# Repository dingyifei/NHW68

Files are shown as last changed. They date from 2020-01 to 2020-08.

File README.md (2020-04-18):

# Not Hand Wired 68 Keys

## License

This project (not include ./hardware/KiCad/, ./code, or files with licenses inside them) is using MIT license.

If not specified, the files in ./code are GPL V2

## Code

Code should be functional, haven't push it to QMK or tested on the keyboard yet, compile passed.

## Hardware

I'm attempting to draw the PCB and its my first time drawing a PCB so 0 confidence it will work. I did my research and if you want to use it plz do your own research make sure it works.

I have not yet tested the PCB, the keyboard PCB currently looks like this:

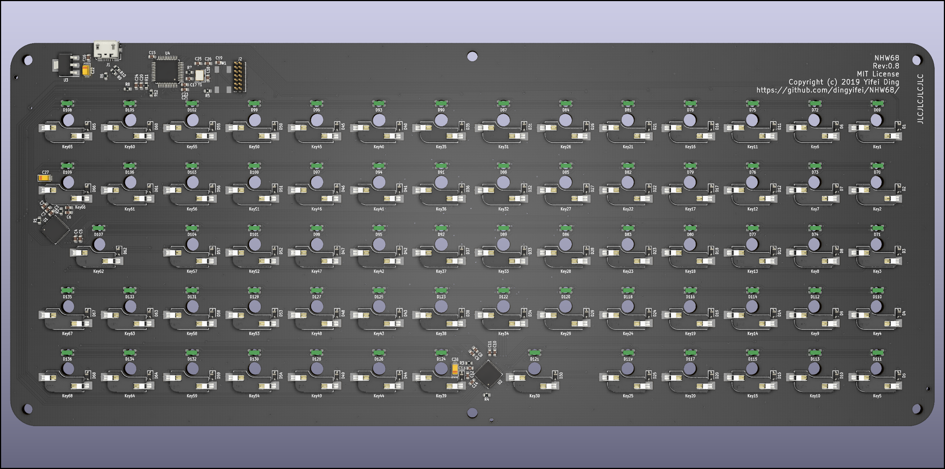
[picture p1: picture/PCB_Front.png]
PCB_Front


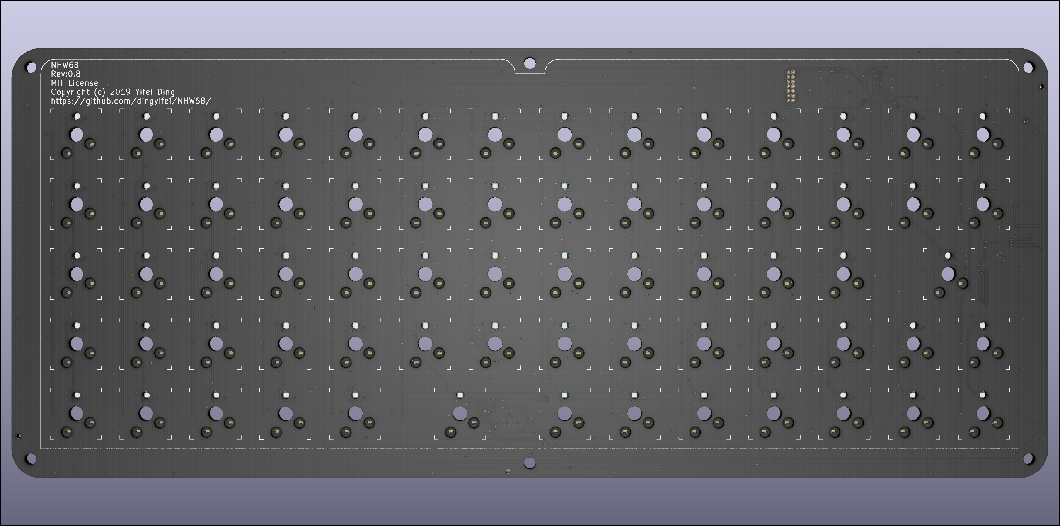
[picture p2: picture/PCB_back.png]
PCB_Back


The keyboard uses STM32F303CCT6, IS31FL3733 and have per Key RGB. 

The RGB is optional since it can work without RGB (I believe most people can live without RGB :p)

Here is the fusion 360 3d mode, I think it is good enough

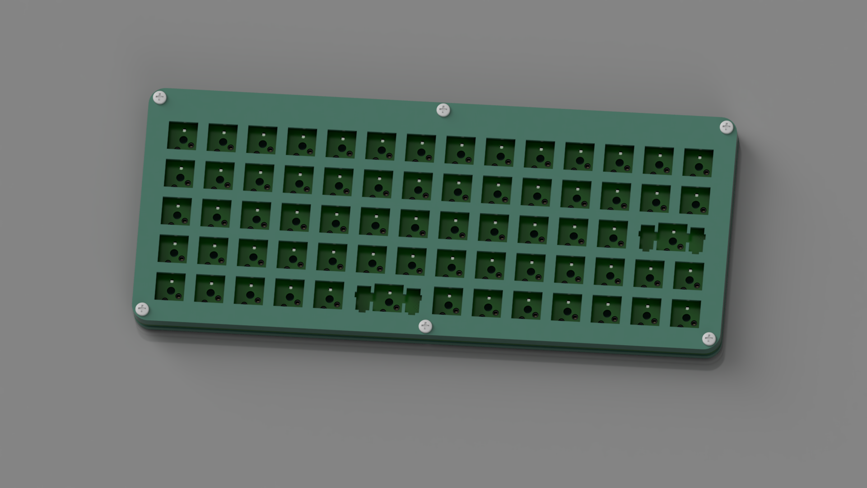
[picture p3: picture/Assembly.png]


Fusion 360 Link: https://a360.co/2X8L0Fb

**Note: The screws and nuts are downloaded 3D model from misumi, license info can be found on misumi website**

## Layout

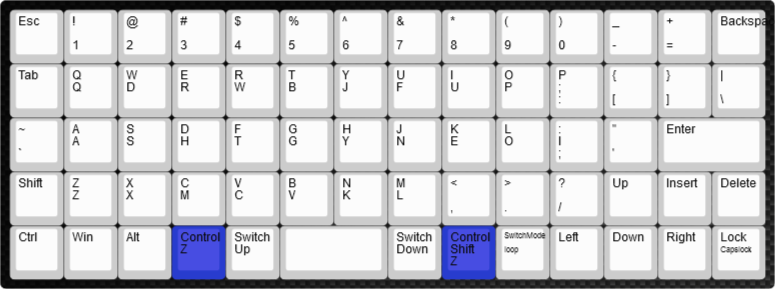
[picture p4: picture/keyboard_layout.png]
keyboard-layout


The blue keys' function depend on use case

## Assembly

Stacking: 

1. Plate(1.6mm)
2. Spacer(1.2mm)x3
3. PCB(1.6mm)
4. Nuts(2.4mm or more)
5. Spacer(1.2mm)
6. Base(1.6mm)
7. Nuts(2.4mm)

Use 16mm~18mm M3 screw and nuts should be just fine, a PCB fab usually provide 1.6mm and 1.2mm.

Note: Manually cut 2 spacer PCB can replace the 4. Nuts but it would mean you need to choose "Order 10" option in the most fabs (which would increase the difficulty in sourcing all the parts)

## Cost

5 piece of (Spacer, PCB, Plate, Base) - $70 if you choose leaded HSAL

Parts are relatively cheap and you don't have to worry about them, LCSC is a good place to get all those parts(u probably need Amazon for Kailh hot swap, DigiKey for RGB controller)

## Release V1.1 

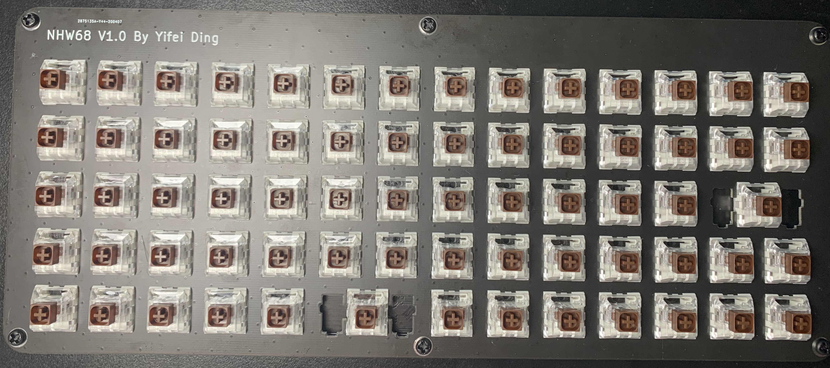
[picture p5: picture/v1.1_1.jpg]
v1.1-1


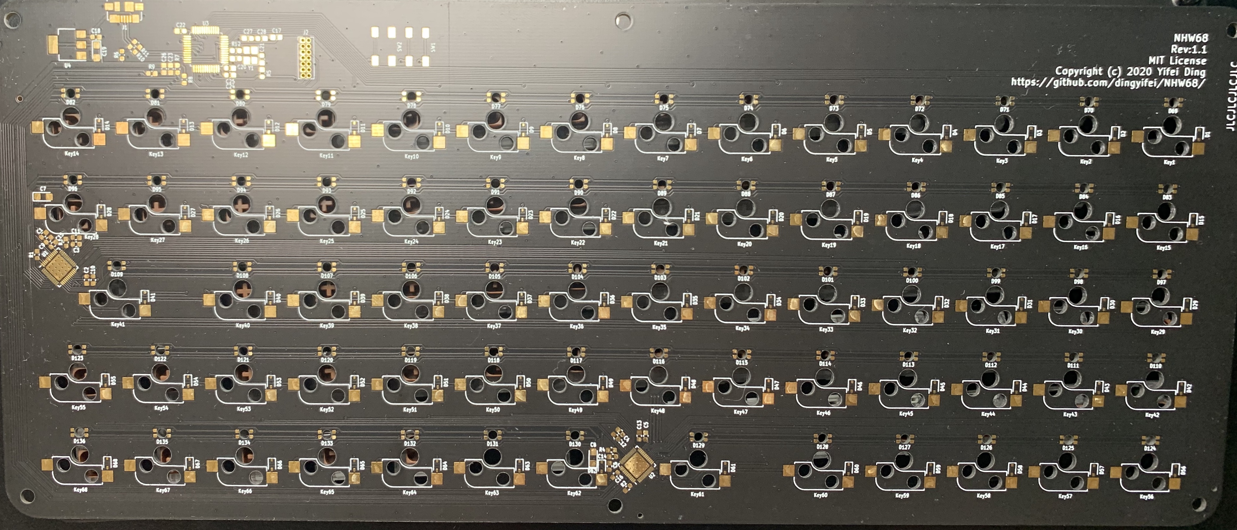
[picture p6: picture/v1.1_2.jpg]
v1.1-2


#### Known Problems

1. Key Caps are hard to find
2. Center is 2u left
3. RGB LED footprint is WRONG and WON'T WORK

4. 0 ESD protection

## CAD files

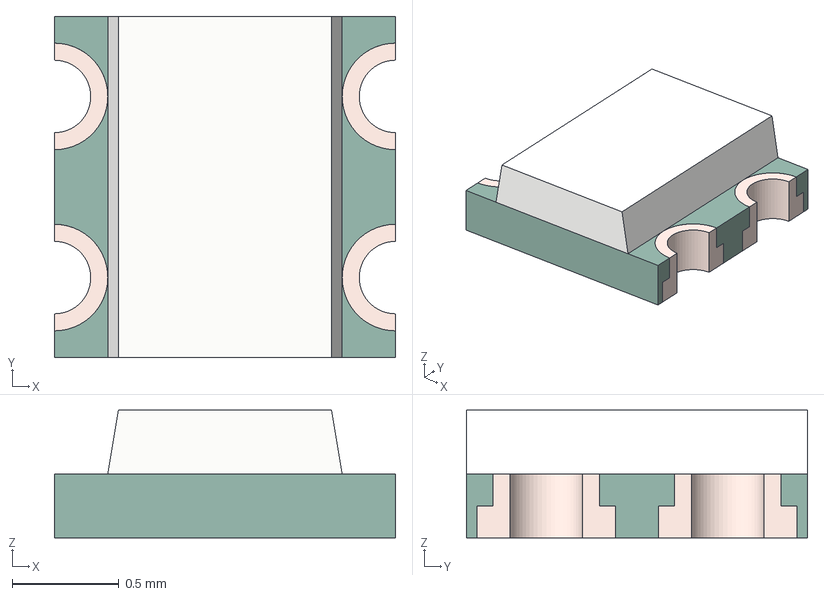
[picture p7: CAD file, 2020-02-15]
hardware/KiCad/0606_1616_h0.6mmRGB.step
1.60 x 1.60 x 0.6 mm
零部件1
零部件2
零部件3

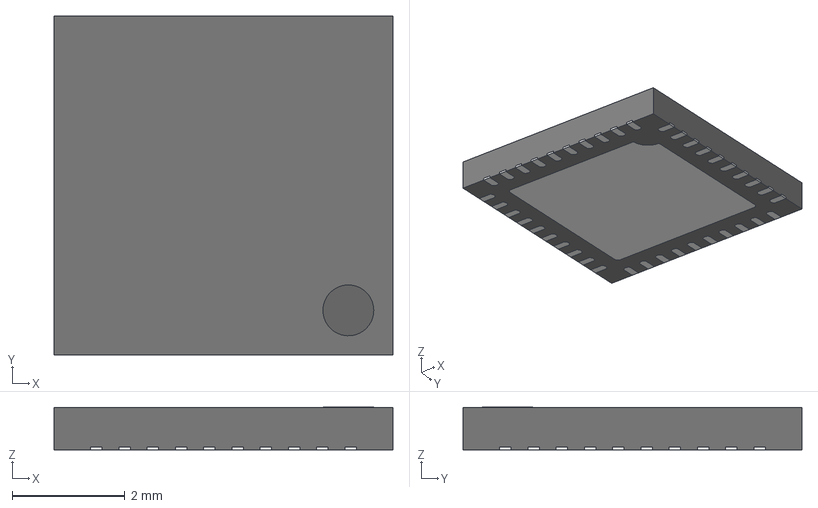
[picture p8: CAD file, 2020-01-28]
hardware/KiCad/QFN40.step
6.00 x 6.00 x 0.76 mm
零部件1
零部件2
零部件3

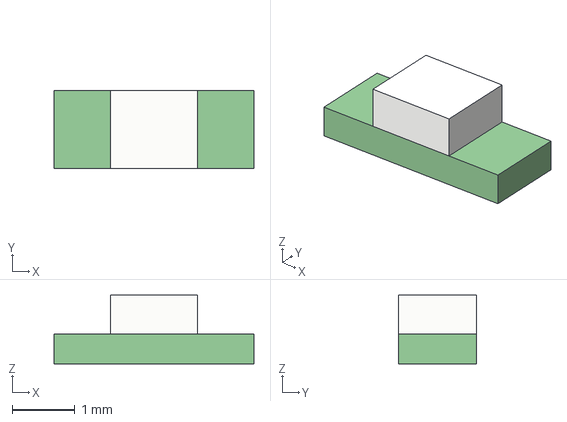
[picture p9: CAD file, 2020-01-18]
hardware/KiCad/MHT150RGBCT v1.step
3.20 x 1.25 x 1.10 mm
零部件1
零部件2

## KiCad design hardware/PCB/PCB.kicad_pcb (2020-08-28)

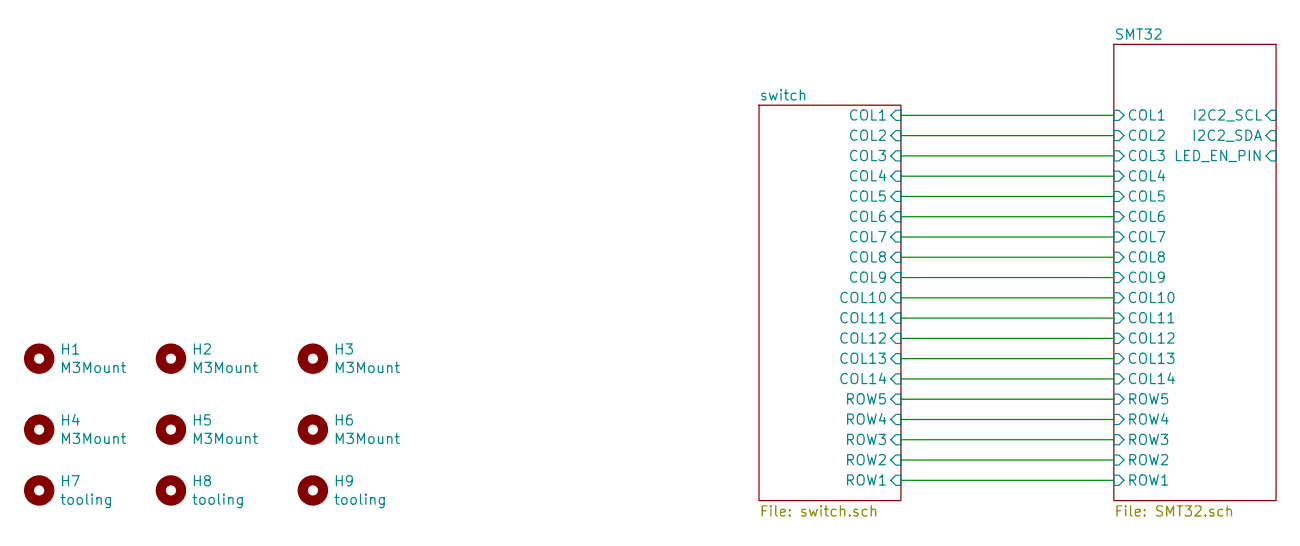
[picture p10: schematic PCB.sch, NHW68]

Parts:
H1, H2, H3, H4, H5, H6: M3Mount; MountingHole_3.2mm_M3_DIN965
H7, H8, H9: tooling; JLC_SMT_ToolingHole

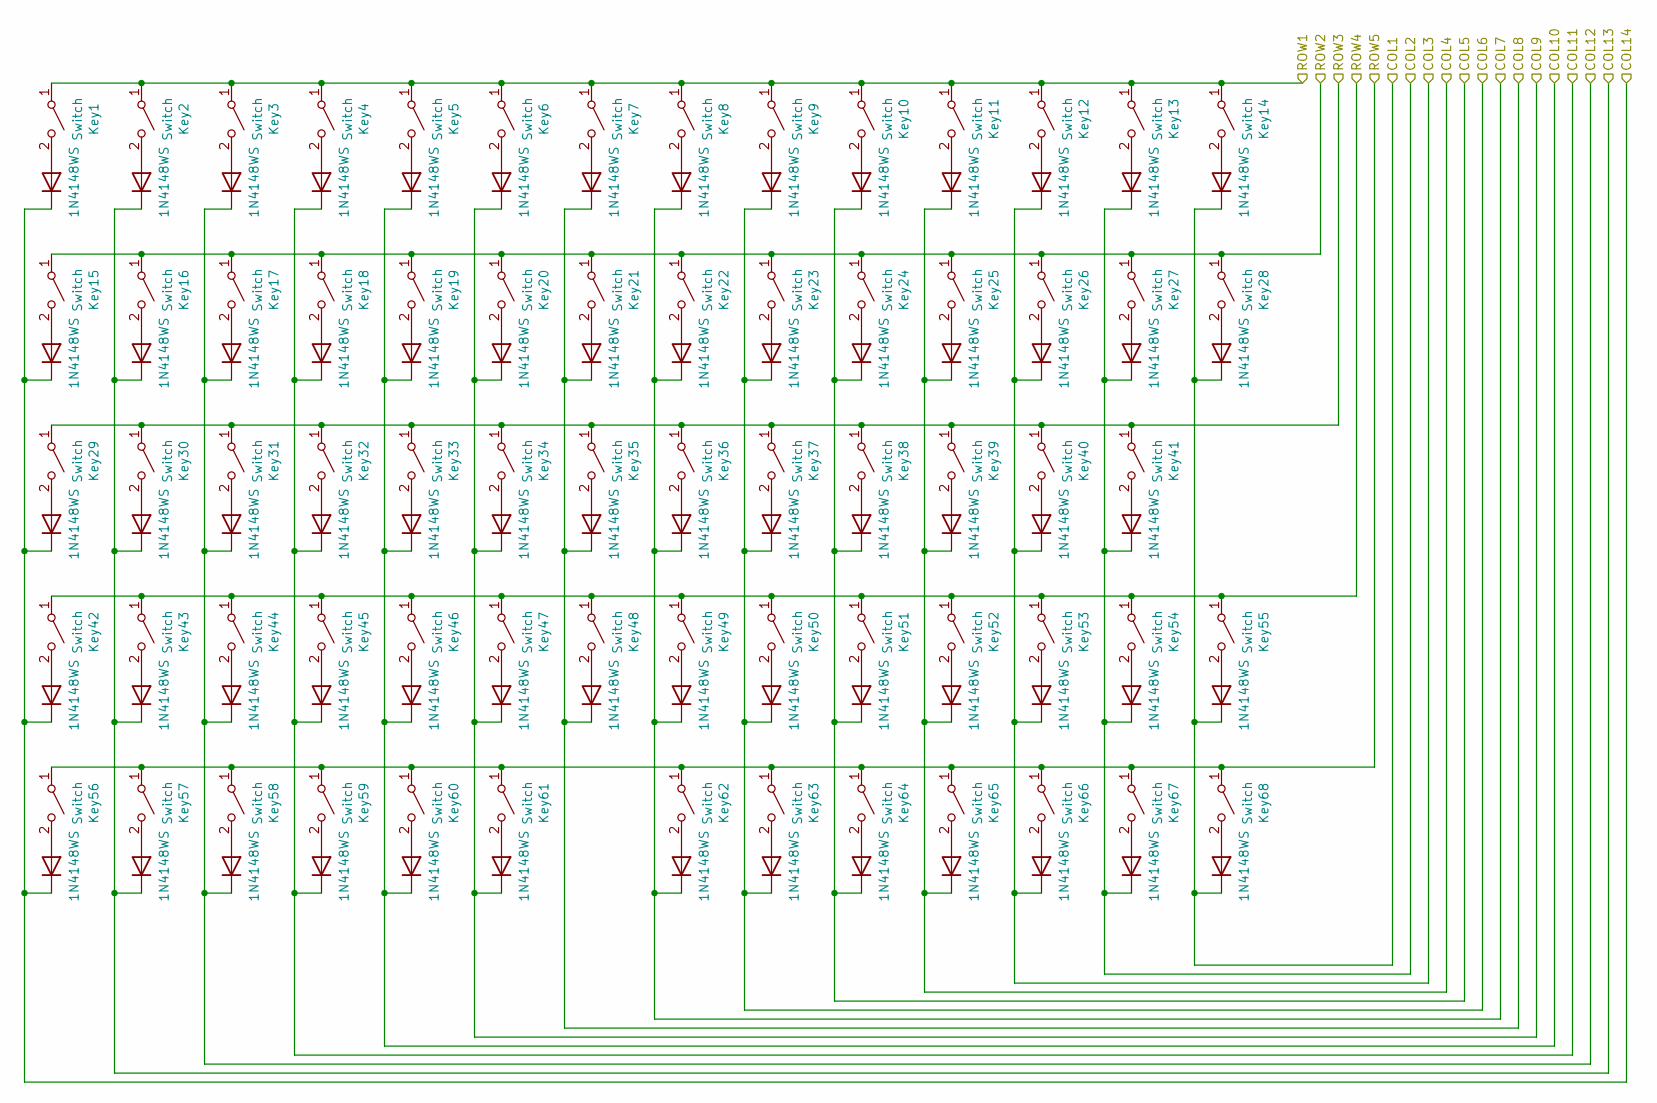
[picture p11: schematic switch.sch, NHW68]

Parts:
D1, D2, D3, D4, D5, D6, D7, D8, D9, D10, D11, D12, D13, D14, D15, D16, D17, D18, D19, D20, D21, D22, D23, D24, D25, D26, D27, D28, D29, D30, D31, D32, D33, D34, D35, D36, D37, D38, D39, D40, D41, D42, D43, D44, D45, D46, D47, D48, D49, D50, D51, D52, D53, D54, D55, D56, D57, D58, D59, D60, D61, D62, D63, D64, D65, D66, D67, D68: 1N4148WS; D_SOD-323; Part Number 1N4148WS; LCSC C110221
Key1, Key2, Key3, Key4, Key5, Key6, Key7, Key8, Key9, Key10, Key11, Key12, Key13, Key14, Key15, Key16, Key17, Key18, Key19, Key20, Key21, Key22, Key23, Key24, Key25, Key26, Key27, Key28, Key29, Key30, Key31, Key32, Key33, Key34, Key35, Key36, Key37, Key38, Key39, Key40, Key41, Key42, Key43, Key44, Key45, Key46, Key47, Key48, Key49, Key50, Key51, Key52, Key53, Key54, Key55, Key56, Key57, Key58, Key59, Key60, Key61, Key62, Key63, Key64, Key65, Key66, Key67, Key68: Switch; Kailh_socket_MX_simplified; Part Number CPG151101S11

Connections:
/SMT32/COL1: D14.1 (K), D28.1 (K), D55.1 (K), D68.1 (K); also elsewhere on the board
/SMT32/COL2: D13.1 (K), D27.1 (K), D41.1 (K), D54.1 (K), D67.1 (K); also elsewhere on the board
/SMT32/COL3: D12.1 (K), D26.1 (K), D40.1 (K), D53.1 (K), D66.1 (K); also elsewhere on the board
/SMT32/COL4: D11.1 (K), D25.1 (K), D39.1 (K), D52.1 (K), D65.1 (K); also elsewhere on the board
/SMT32/COL5: D10.1 (K), D24.1 (K), D38.1 (K), D51.1 (K), D64.1 (K); also elsewhere on the board
/SMT32/COL6: D9.1 (K), D23.1 (K), D37.1 (K), D50.1 (K), D63.1 (K); also elsewhere on the board
/SMT32/COL7: D8.1 (K), D22.1 (K), D36.1 (K), D49.1 (K), D62.1 (K); also elsewhere on the board
/SMT32/COL8: D7.1 (K), D21.1 (K), D35.1 (K), D48.1 (K); also elsewhere on the board
/SMT32/COL9: D6.1 (K), D20.1 (K), D34.1 (K), D47.1 (K), D61.1 (K); also elsewhere on the board
/SMT32/COL10: D5.1 (K), D19.1 (K), D33.1 (K), D46.1 (K), D60.1 (K); also elsewhere on the board
/SMT32/COL11: D4.1 (K), D18.1 (K), D32.1 (K), D45.1 (K), D59.1 (K); also elsewhere on the board
/SMT32/COL12: D3.1 (K), D17.1 (K), D31.1 (K), D44.1 (K), D58.1 (K); also elsewhere on the board
/SMT32/COL13: D2.1 (K), D16.1 (K), D30.1 (K), D43.1 (K), D57.1 (K); also elsewhere on the board
/SMT32/COL14: D1.1 (K), D15.1 (K), D29.1 (K), D42.1 (K), D56.1 (K); also elsewhere on the board
/SMT32/ROW1: Key1.1 (A), Key2.1 (A), Key3.1 (A), Key4.1 (A), Key5.1 (A), Key6.1 (A), Key7.1 (A), Key8.1 (A), Key9.1 (A), Key10.1 (A), Key11.1 (A), Key12.1 (A), Key13.1 (A), Key14.1 (A); also elsewhere on the board
/SMT32/ROW2: Key15.1 (A), Key16.1 (A), Key17.1 (A), Key18.1 (A), Key19.1 (A), Key20.1 (A), Key21.1 (A), Key22.1 (A), Key23.1 (A), Key24.1 (A), Key25.1 (A), Key26.1 (A), Key27.1 (A), Key28.1 (A); also elsewhere on the board
/SMT32/ROW3: Key29.1 (A), Key30.1 (A), Key31.1 (A), Key32.1 (A), Key33.1 (A), Key34.1 (A), Key35.1 (A), Key36.1 (A), Key37.1 (A), Key38.1 (A), Key39.1 (A), Key40.1 (A), Key41.1 (A); also elsewhere on the board
/SMT32/ROW4: Key42.1 (A), Key43.1 (A), Key44.1 (A), Key45.1 (A), Key46.1 (A), Key47.1 (A), Key48.1 (A), Key49.1 (A), Key50.1 (A), Key51.1 (A), Key52.1 (A), Key53.1 (A), Key54.1 (A), Key55.1 (A); also elsewhere on the board
/SMT32/ROW5: Key56.1 (A), Key57.1 (A), Key58.1 (A), Key59.1 (A), Key60.1 (A), Key61.1 (A), Key62.1 (A), Key63.1 (A), Key64.1 (A), Key65.1 (A), Key66.1 (A), Key67.1 (A), Key68.1 (A); also elsewhere on the board
unnamed: D1.2 (A), Key1.2 (B)
unnamed: D2.2 (A), Key2.2 (B)
unnamed: D3.2 (A), Key3.2 (B)
unnamed: D4.2 (A), Key4.2 (B)
unnamed: D5.2 (A), Key5.2 (B)
unnamed: D6.2 (A), Key6.2 (B)
unnamed: D7.2 (A), Key7.2 (B)
unnamed: D8.2 (A), Key8.2 (B)
unnamed: D9.2 (A), Key9.2 (B)
unnamed: D10.2 (A), Key10.2 (B)
unnamed: D11.2 (A), Key11.2 (B)
unnamed: D12.2 (A), Key12.2 (B)
unnamed: D13.2 (A), Key13.2 (B)
unnamed: D14.2 (A), Key14.2 (B)
unnamed: D15.2 (A), Key15.2 (B)
unnamed: D16.2 (A), Key16.2 (B)
unnamed: D17.2 (A), Key17.2 (B)
unnamed: D18.2 (A), Key18.2 (B)
unnamed: D19.2 (A), Key19.2 (B)
unnamed: D20.2 (A), Key20.2 (B)
unnamed: D21.2 (A), Key21.2 (B)
unnamed: D22.2 (A), Key22.2 (B)
unnamed: D23.2 (A), Key23.2 (B)
unnamed: D24.2 (A), Key24.2 (B)
unnamed: D25.2 (A), Key25.2 (B)
unnamed: D26.2 (A), Key26.2 (B)
unnamed: D27.2 (A), Key27.2 (B)
unnamed: D28.2 (A), Key28.2 (B)
unnamed: D29.2 (A), Key29.2 (B)
unnamed: D30.2 (A), Key30.2 (B)
unnamed: D31.2 (A), Key31.2 (B)
unnamed: D32.2 (A), Key32.2 (B)
unnamed: D33.2 (A), Key33.2 (B)
unnamed: D34.2 (A), Key34.2 (B)
unnamed: D35.2 (A), Key35.2 (B)
unnamed: D36.2 (A), Key36.2 (B)
unnamed: D37.2 (A), Key37.2 (B)
unnamed: D38.2 (A), Key38.2 (B)
unnamed: D39.2 (A), Key39.2 (B)
unnamed: D40.2 (A), Key40.2 (B)
unnamed: D41.2 (A), Key41.2 (B)
unnamed: D42.2 (A), Key42.2 (B)
unnamed: D43.2 (A), Key43.2 (B)
unnamed: D44.2 (A), Key44.2 (B)
unnamed: D45.2 (A), Key45.2 (B)
unnamed: D46.2 (A), Key46.2 (B)
unnamed: D47.2 (A), Key47.2 (B)
unnamed: D48.2 (A), Key48.2 (B)
unnamed: D49.2 (A), Key49.2 (B)
unnamed: D50.2 (A), Key50.2 (B)
unnamed: D51.2 (A), Key51.2 (B)
unnamed: D52.2 (A), Key52.2 (B)
unnamed: D53.2 (A), Key53.2 (B)
unnamed: D54.2 (A), Key54.2 (B)
unnamed: D55.2 (A), Key55.2 (B)
unnamed: D56.2 (A), Key56.2 (B)
unnamed: D57.2 (A), Key57.2 (B)
unnamed: D58.2 (A), Key58.2 (B)
unnamed: D59.2 (A), Key59.2 (B)
unnamed: D60.2 (A), Key60.2 (B)
unnamed: D61.2 (A), Key61.2 (B)
unnamed: D62.2 (A), Key62.2 (B)
unnamed: D63.2 (A), Key63.2 (B)
unnamed: D64.2 (A), Key64.2 (B)
unnamed: D65.2 (A), Key65.2 (B)
unnamed: D66.2 (A), Key66.2 (B)
unnamed: D67.2 (A), Key67.2 (B)
unnamed: D68.2 (A), Key68.2 (B)

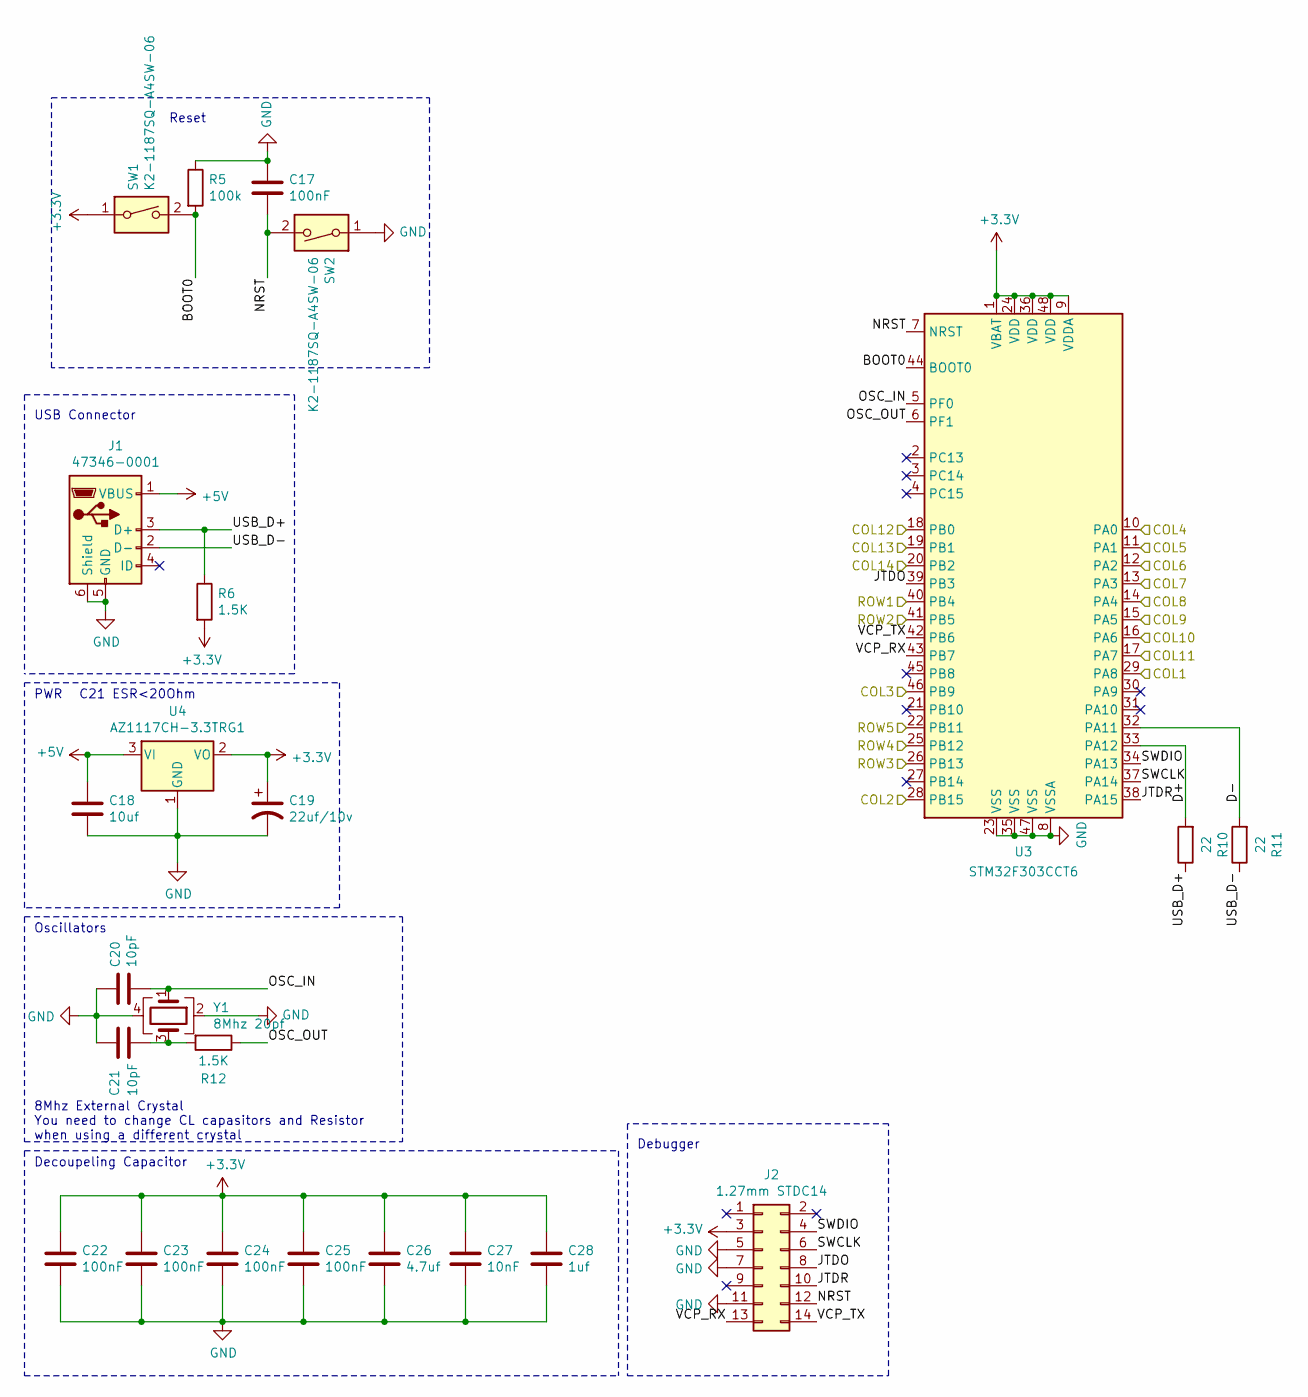
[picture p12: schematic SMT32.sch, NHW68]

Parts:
C17, C22, C23, C24, C25: 100nF; C_0603_1608Metric; Part Number 0603B104K160CT; LCSC C80516
C18: 10uf; C_0603_1608Metric; Part Number 0603X106K100NT; LCSC C38898
C19: 22uf/10v; CP_EIA-3216-18_Kemet-A; Part Number TAJA226K010RNJ; LCSC C11366
C20, C21: 10pF; C_0603_1608Metric; Part Number CC0603GRNPO9BN100; LCSC C325468
C26: 4.7uf; C_0603_1608Metric; Part Number CL10A475KA8NQNC; LCSC C69335
C27: 10nF; C_0603_1608Metric; Part Number CL10B103JB8NNNC; LCSC C7248
C28: 1uf; C_0603_1608Metric; Part Number UMK107AB7105KA-T; LCSC C105174
J1: 47346-0001; USB_Micro-B_Molex_47346-0001; Part Number 47346-0001; LCSC C132560
J2: 1.27mm STDC14; PinHeader_2x07_P1.27mm_Vertical
R5: 100k; R_0603_1608Metric; Part Number CR0603FA1003G; LCSC C100703
R6, R12: 1.5K; R_0603_1608Metric; Part Number RTT031501FTP; LCSC C103303
R10, R11: 22; R_0603_1608Metric; Part Number CR0603FA22R0G; LCSC C100876
SW1, SW2: K2-1187SQ-A4SW-06; Part Number K2-1187SQ-A4SW-06; LCSC C92584
U3: STM32F303CCT6; LQFP-48_7x7mm_P0.5mm; Part Number STM32F303CCT6; LCSC C81523
U4: AZ1117CH-3.3TRG1; SOT-223-3_TabPin2; Part Number AZ1117CH-3.3TRG1; LCSC C92102
Y1: 8Mhz 20pf; Crystal_SMD_3225-4Pin_3.2x2.5mm; Part Number TAXM8M4RDBCCT2T; LCSC C400090

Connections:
+3V3: C19.1, C22.1, C23.1, C24.1, C25.1, C26.1, C27.1, C28.1, J2.3, R6.2, SW1.1, U3.1 (VBAT), U3.9 (VDDA), U3.24 (VDD), U3.36 (VDD), U3.48 (VDD), U4.2 (VO)
+5V: C18.1, J1.1 (VBUS), U4.3 (VI)
/SMT32/BOOT0: R5.2, SW1.2, U3.44 (BOOT0)
/SMT32/COL1: U3.29 (PA8); also elsewhere on the board
/SMT32/COL2: U3.28 (PB15); also elsewhere on the board
/SMT32/COL3: U3.46 (PB9); also elsewhere on the board
/SMT32/COL4: U3.10 (PA0); also elsewhere on the board
/SMT32/COL5: U3.11 (PA1); also elsewhere on the board
/SMT32/COL6: U3.12 (PA2); also elsewhere on the board
/SMT32/COL7: U3.13 (PA3); also elsewhere on the board
/SMT32/COL8: U3.14 (PA4); also elsewhere on the board
/SMT32/COL9: U3.15 (PA5); also elsewhere on the board
/SMT32/COL10: U3.16 (PA6); also elsewhere on the board
/SMT32/COL11: U3.17 (PA7); also elsewhere on the board
/SMT32/COL12: U3.18 (PB0); also elsewhere on the board
/SMT32/COL13: U3.19 (PB1); also elsewhere on the board
/SMT32/COL14: U3.20 (PB2); also elsewhere on the board
/SMT32/D+: R10.2, U3.33 (PA12)
/SMT32/D-: R11.2, U3.32 (PA11)
/SMT32/JTDO: J2.8, U3.39 (PB3)
/SMT32/JTDR: J2.10, U3.38 (PA15)
/SMT32/NRST: C17.2, J2.12, SW2.2, U3.7 (NRST)
/SMT32/OSC_IN: C20.2, U3.5 (PF0), Y1.1
/SMT32/OSC_OUT: R12.1, U3.6 (PF1)
/SMT32/ROW1: U3.40 (PB4); also elsewhere on the board
/SMT32/ROW2: U3.41 (PB5); also elsewhere on the board
/SMT32/ROW3: U3.26 (PB13); also elsewhere on the board
/SMT32/ROW4: U3.25 (PB12); also elsewhere on the board
/SMT32/ROW5: U3.22 (PB11); also elsewhere on the board
/SMT32/SWCLK: J2.6, U3.37 (PA14)
/SMT32/SWDIO: J2.4, U3.34 (PA13)
/SMT32/USB_D+: J1.3 (D+), R6.1, R10.1
/SMT32/USB_D-: J1.2 (D-), R11.1
/SMT32/VCP_RX: J2.13, U3.43 (PB7)
/SMT32/VCP_TX: J2.14, U3.42 (PB6)
GND: C17.1, C18.2, C19.2, C20.1, C21.1, C22.2, C23.2, C24.2, C25.2, C26.2, C27.2, C28.2, J1.5 (GND), J1.6 (Shield), J2.5, J2.7, J2.11, R5.1, SW2.1, U3.8 (VSSA), U3.23 (VSS), U3.35 (VSS), U3.47 (VSS), U4.1 (GND), Y1.2, Y1.4
unnamed: C21.2, R12.2, Y1.3

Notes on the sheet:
PWR
C21 ESR<20Ohm
8Mhz External Crystal You need to change CL capasitors and Resistor when using a different crystal
USB Connector
Oscillators
Decoupeling Capacitor
Debugger
Reset

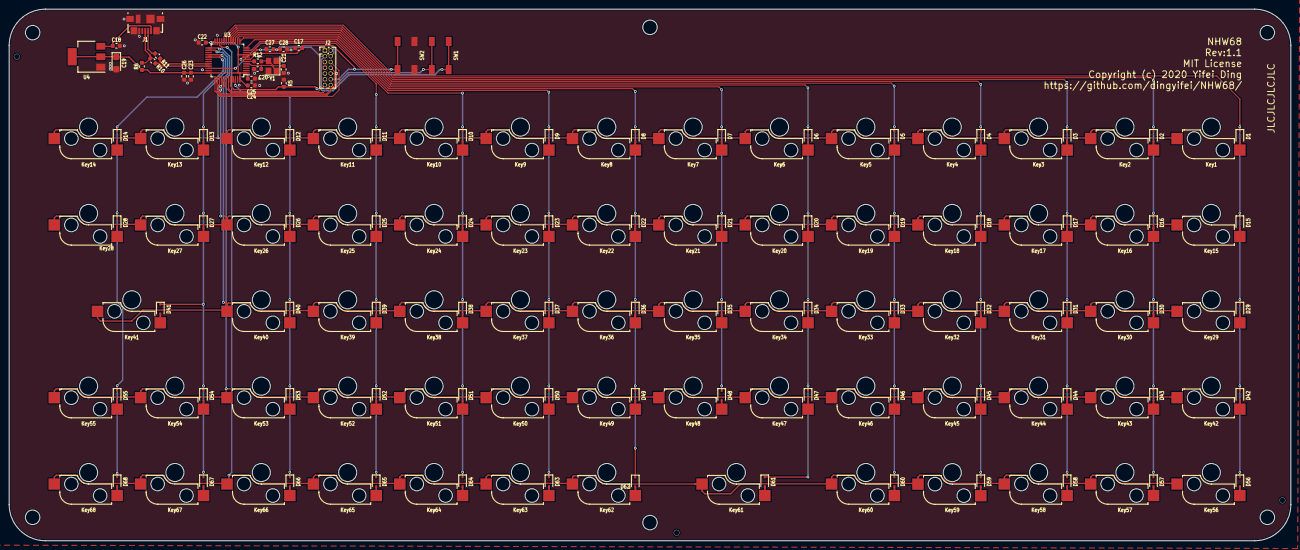
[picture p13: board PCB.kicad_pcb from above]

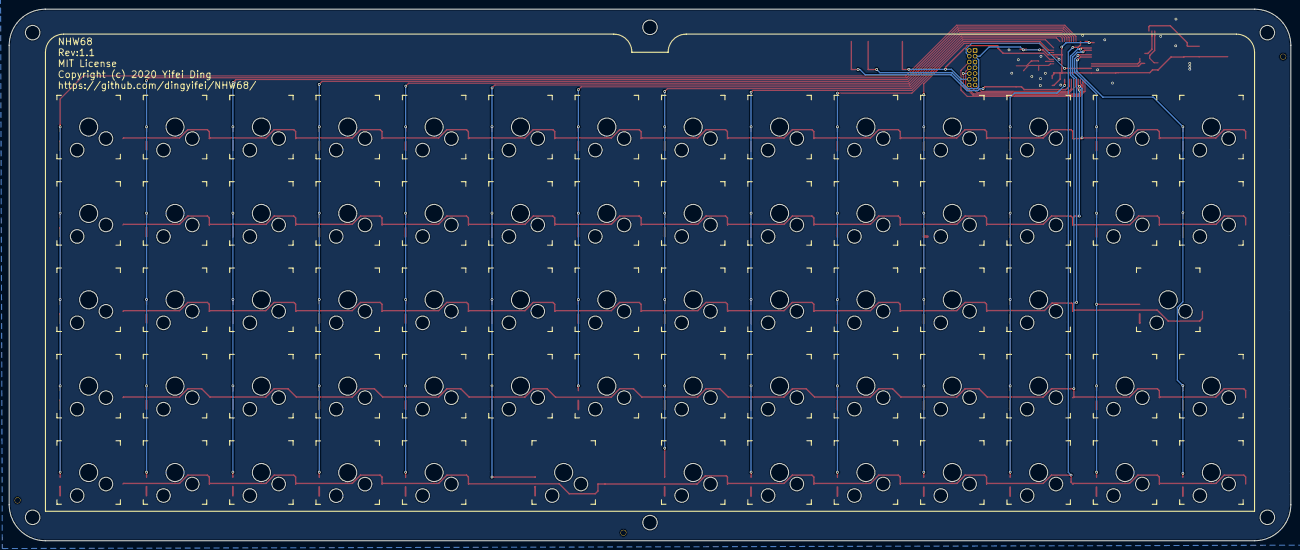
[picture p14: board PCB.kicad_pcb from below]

Board: 2 copper layers, 282.7 x 117.3 mm, 169 parts (68 on the bottom side), 105 nets.

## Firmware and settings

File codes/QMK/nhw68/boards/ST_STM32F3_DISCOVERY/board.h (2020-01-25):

/*
    ChibiOS - Copyright (C) 2006..2018 Giovanni Di Sirio

    Licensed under the Apache License, Version 2.0 (the "License");
    you may not use this file except in compliance with the License.
    You may obtain a copy of the License at

        http://www.apache.org/licenses/LICENSE-2.0

    Unless required by applicable law or agreed to in writing, software
    distributed under the License is distributed on an "AS IS" BASIS,
    WITHOUT WARRANTIES OR CONDITIONS OF ANY KIND, either express or implied.
    See the License for the specific language governing permissions and
    limitations under the License.
*/

/*
 * This file has been automatically generated using ChibiStudio board
 * generator plugin. Do not edit manually.
 */

#ifndef BOARD_H
#define BOARD_H

/*===========================================================================*/
/* Driver constants.                                                         */
/*===========================================================================*/

/*
 * Setup for STMicroelectronics STM32F3-Discovery board.
 */

/*
 * Board identifier.
 */
#define BOARD_ST_STM32F3_DISCOVERY
#define BOARD_NAME                  "STMicroelectronics STM32F3-Discovery"

/*
 * Board oscillators-related settings.
 * NOTE: LSE not fitted.
 */
#if !defined(STM32_LSECLK)
#define STM32_LSECLK                0U
#endif

#define STM32_LSEDRV                (3U << 3U)

#if !defined(STM32_HSECLK)
#define STM32_HSECLK                8000000U
#endif

#define STM32_HSE_BYPASS

/*
 * MCU type as defined in the ST header.
 */
#define STM32F303xC

/*
 * IO pins assignments.
 */
#define GPIOA_BUTTON                0U
#define GPIOA_PIN1                  1U
#define GPIOA_PIN2                  2U
#define GPIOA_PIN3                  3U
#define GPIOA_PIN4                  4U
#define GPIOA_SPI1_SCK              5U
#define GPIOA_L3GD20_SCL            5U
#define GPIOA_SPI1_MISO             6U
#define GPIOA_L3GD20_SDO            6U
#define GPIOA_SPI1_MOSI             7U
#define GPIOA_L3GD20_SDI            7U
#define GPIOA_PIN8                  8U
#define GPIOA_PIN9                  9U
#define GPIOA_PIN10                 10U
#define GPIOA_USB_DM                11U
#define GPIOA_USB_DP                12U
#define GPIOA_SWDIO                 13U
#define GPIOA_SWCLK                 14U
#define GPIOA_PIN15                 15U

#define GPIOB_PIN0                  0U
#define GPIOB_PIN1                  1U
#define GPIOB_PIN2                  2U
#define GPIOB_SWO                   3U
#define GPIOB_PIN4                  4U
#define GPIOB_PIN5                  5U
#define GPIOB_I2C1_SCL              6U
#define GPIOB_LSM303DLHC_SCL        6U
#define GPIOB_I2C1_SDA              7U
#define GPIOB_LSM303DLHC_SDA        7U
#define GPIOB_PIN8                  8U
#define GPIOB_PIN9                  9U
#define GPIOB_PIN10                 10U
#define GPIOB_PIN11                 11U
#define GPIOB_PIN12                 12U
#define GPIOB_PIN13                 13U
#define GPIOB_PIN14                 14U
#define GPIOB_PIN15                 15U

#define GPIOC_PIN0                  0U
#define GPIOC_PIN1                  1U
#define GPIOC_PIN2                  2U
#define GPIOC_PIN3                  3U
#define GPIOC_VCP_RX                4U
#define GPIOC_VCP_TX                5U
#define GPIOC_PIN6                  6U
#define GPIOC_PIN7                  7U
#define GPIOC_PIN8                  8U
#define GPIOC_PIN9                  9U
#define GPIOC_PIN10                 10U
#define GPIOC_PIN11                 11U
#define GPIOC_PIN12                 12U
#define GPIOC_PIN13                 13U
#define GPIOC_OSC32_IN              14U
#define GPIOC_OSC32_OUT             15U

#define GPIOD_PIN0                  0U
#define GPIOD_PIN1                  1U
#define GPIOD_PIN2                  2U
#define GPIOD_PIN3                  3U
#define GPIOD_PIN4                  4U
#define GPIOD_PIN5                  5U
#define GPIOD_PIN6                  6U
#define GPIOD_PIN7                  7U
#define GPIOD_PIN8                  8U
#define GPIOD_PIN9                  9U
#define GPIOD_PIN10                 10U
#define GPIOD_PIN11                 11U
#define GPIOD_PIN12                 12U
#define GPIOD_PIN13                 13U
#define GPIOD_PIN14                 14U
#define GPIOD_PIN15                 15U
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

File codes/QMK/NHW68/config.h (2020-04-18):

/*
Copyright (C) 2020 Yifei Ding <dingyifeiair@gmail.com> <yifeiding@protonmail.com>

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
You should have received a copy of the GNU General Public License along with
this program.  If not, see <http://www.gnu.org/licenses/>.
*/

#include "config_common.h"

#define VENDOR_ID 0x2333
#define PRODUCT_ID 0x2333
#define DEVICE_VER 0.1
#define MANUFACTURE "Who Knows"
#define PRODUCT "NHW68"
#define DESCRIPTION "It is a functional keyboard"
#define MATRIX_ROWS 5
#define MATRIX_COLS 14
#define MATRIX_ROW_PINS {B4, B5, B13, B12, B11}
#define MATRIX_COL_PINS {B2, B1, B0, A7, A6, A5, A4, A3, A2, A1, A0, B9, B15, A8}
#define UNUSED_PINS {C13, C14, C15, B8, B10}
#define DIODE_DIRECTION ROW2COL
#define USB_MAX_POWER_CONSUMPTION 244
#define F_SCL 400000L
#include "config_led.h"

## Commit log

2019-12-29 At least I'm working on it....
    [RGB.sch, RGBMatrix2.sch, RGBmatrix.sch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]
2019-12-31 I think im connecting the pins correctly on RGB...
    [RGB.sch, RGBMatrix2.sch, RGBmatrix.sch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]
2020-01-01 switch to proper type of RGB(Common anode)
    [RGB.sch, RGBMatrix2.sch, RGBmatrix.sch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]
2020-01-01 Use proper capacitors
    [RGB.sch]
2020-01-01 fix unconnected rgb
    [RGB.sch, RGBMatrix2.sch, RGBmatrix.sch]
2020-01-01 now it should be using the correct rgb symbol (RABG)
    [RGBMatrix2.sch, RGBmatrix.sch]
2020-01-01 use proper footprint, link symbols and footprints
    [RGB.sch, RGBMatrix2.sch, RGBmatrix.sch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]
2020-01-01 make everything cleaner
    [RGB.sch]
2020-01-01 finally the net is kinda working
    [keyboard.kicad_pcb, keyboard.sch]
2020-01-03 outline done
    [PCBSpacing.dxf, RGB.sch, RGBMatrix2.sch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]
2020-01-04 Line up most parts and fix some problems with the part
    1.Fix the LED footprint size
    2.Edit the hotplug to be simpler (removed 2 holes)
    3.Line up everything and the silkscreen
    4. Fix the LED matrix and the switch matrix sch
    [RGBMatrix2.sch, RGBmatrix.sch, keyboard.kicad_pcb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]
2020-01-06 I think I figured it out
    [RGB.sch, RGBMatrix2.sch, RGBmatrix.sch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]
2020-01-06 The keys are finally connected
    [keyboard.kicad_pcb]
2020-01-07 Make it better by get rid of the protonC
    1. Remove protonC. use STM32F303CCT6 instead
    2.Use parts based on avalibility
    3.Extend the case so it now fits more parts( should be big enough
    4. A reasonable USB connector
    5. Probably a working DC-DC solution to providde 3.3V
    6. Move 3733's 5V to only 3.3V (maybe it won't work?)
    [Cutout.dxf, RGB.sch, SMT32.sch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]
2020-01-07 I think I don't need those pull ups, if i really need it, add them later
    [keyboard.kicad_pcb, switch.sch]
2020-01-10 clear all the traces
    [Cutout.dxf, PCBSpacing.dxf, SMT32.sch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]
2020-01-11 PSU placed
    [RGB.sch, SMT32.sch, XZxxxxxx45S-9.step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]
2020-01-12 PCB is done??
    [SMT32.sch, keyboard.kicad_pcb]
2020-01-13 starting the testing PCB
    [RGB.sch, RGBMatrix2.sch, RGBmatrix.sch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]
2020-01-13 remove useless files
    [RGB.sch, RGBMatrix2.sch, RGBmatrix.sch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]
2020-01-16 making testing PCB, making sure the DFU mode is correct
    [RGB.sch, RGBMatrix2.sch, RGBmatrix.sch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]
2020-01-18 Full Send, SMT assembly LOL
    [SMT32.sch, keyboard.kicad_pcb, switch.sch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]
2020-01-18 small changes
    [MHT150RGBCT v1.step, SMT32.sch, SpareParts.sch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]
2020-01-23 Making progress, so many distance warning!!!
    [RGB.sch, RGBmatrix.sch, SMT32.sch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]
2020-01-24 Rotate the RGB controller. gonna have a lot of work to do
    [SMT32.sch, keyboard.kicad_pcb, switch.sch]
2020-01-25 getting closer to it actually works
    [RGB.sch, SMT32.sch, keyboard.kicad_pcb]
2020-01-25 Use the correct Footprint
    I think I can't do more things before the parts arrive and figure out what LED im going to use
    [RGB.sch, SMT32.sch, keyboard.kicad_pcb]
2020-01-26 Im not sure I really need this board config thing
2020-01-28 alot of changes
    modify the QFN-48 so PCB 3d view in future would look better (so I don't design a part that doesn't fit)
    I made a useless QFN-40 3d model
    modify schematics so it looks better
    [QFN40.step, RGB.sch, RGBMatrix2.sch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]
2020-01-29 Clear the errors
    [keyboard.kicad_pcb]
2020-01-29 Connecting RGBs
    [RGB.sch, keyboard.kicad_pcb]
2020-01-29 I guess it is done, maybe just make it?
    [keyboard-B_Cu.gbr, keyboard-B_Mask.gbr, keyboard-B_Paste.gbr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]
2020-01-30 making progress
    [MCU_testing.kicad_pcb, MCU_testing.sch, RGB.sch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]
2020-01-31 Wiring now have no errors and uses less vias
    [RGB.sch, keyboard.kicad_pcb]
2020-02-01 minor changes to the LED controller PCB layout, make it much better
    [RGB.sch, keyboard.kicad_pcb]
2020-02-01 Make it nicer, rev0.1 alpha
    [RGB.sch, RGBMatrix2.sch, RGBmatrix.sch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]
2020-02-01 AHHH I can't count, also rename to remove some bugs
    [PCB-B_Cu.gbr, PCB-B_Mask.gbr, PCB-B_Paste.gbr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]
2020-02-01 attempt to remove some extra values
    [PCB.kicad_pcb, SMT32.sch]
2020-02-01 Now it should be working just fine
    [RGB.sch, RGBMatrix2.sch, RGBmatrix.sch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]
2020-02-01 add in part number so I could use it for the bom
    [RGB.sch, RGBMatrix2.sch, RGBmatrix.sch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]
2020-02-02 update render, remove useless files, fix the decoupeling
    [PCB-B_Cu.gbr, PCB-B_Mask.gbr, PCB-B_Paste.gbr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]
2020-02-02 minor changes
    [PCB.kicad_pcb]
2020-02-03 Move the Crystal and made a keepout ring
    [PCB.kicad_pcb]
2020-02-03 small improvements (cap distance)
    [PCB.kicad_pcb, RGBMatrix2.sch, RGBmatrix.sch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]
2020-02-03 vias, don't know why but people put them.... so i put them there just in case
    [PCB.kicad_pcb]
2020-02-04 fix major issues about the I2C pull up, add in debug
    [PCB.kicad_pcb, RGB.sch, SMT32.sch]
2020-02-04 can't do only one commit right?
    [PCB.kicad_pcb]
2020-02-04 always find small things after a commit
    [PCB.kicad_pcb, SMT32.sch]
2020-02-05 Make sure GPL done correctly, rev0.2 ready, not going to make it either
    Need to make it nicer
    [PCB.kicad_pcb, PCB.sch, RGB.sch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]
2020-02-05 I never remember to fix silkscreen...
    [PCB.kicad_pcb]
2020-02-05 I have fish memory
    [PCB.kicad_pcb]
2020-02-05 I don't know why but i can't count
    [PCB.kicad_pcb, PCB.sch, RGB.sch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]
2020-02-05 Testing is going to be a seperate project
    [MCU_testing.kicad_pcb, MCU_testing.sch, RGB.sch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]
2020-02-06 changed something
    [PCB.kicad_pcb, SMT32.sch]
2020-02-07 changed to 0603
    [PCB.kicad_pcb, RGB.sch, SMT32.sch]
2020-02-09 Rev 0.5
    1. Use a better 1205 LED (much chaper on LCSC)
    2. Fix the crystal CL, Rext
    3. did a better job on wiring (but might come with power issues?)
    4. fix the key position (0.01mm shifted so its a big fix)
    5. generate better bom files
    6. add in LCSC and part number so easier to source
    0.4 is gone
    [PCB.kicad_pcb, PCB.sch, RGB.sch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]
2020-02-09 rev 0.5 fixed
    [PCB.kicad_pcb, SMT32.sch]
2020-02-11 0.6 I hate these auto generated code from STM32Cube
    1. ready for the firmware nightmare
    2. adjust the M3 screw holes
    3. add tooling holes for future PCBA
    4. if nothing go wrong, this will be the V1 after testing
    [PCB.kicad_pcb, PCB.sch, RGB.sch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]
2020-02-11 fix some minor detail, I guess its v0.7
    [PCB.kicad_pcb, PCB.sch, RGB.sch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]
2020-02-13 Remove some unused
    [PCB.kicad_pcb, PCB.sch, RGBMatrix2.sch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]
2020-02-13 It is the last update of 1206 RGB design, going to switch LED again, correct the 1206 name
    [PCB.kicad_pcb, RGBMatrix2.sch, RGBmatrix.sch]
2020-02-15 I might just have to stick with 1206/4 did some research, maybe time to make another minimal system board....
    [0606_1616_h0.6mmRGB.step, PCB.kicad_pcb, RGB.sch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]
2020-02-15 fixing the Tantalum
    [PCB.kicad_pcb, RGB.sch, SMT32.sch]
2020-02-16 Code kinda works
    [PCB.kicad_pcb, switch.sch]
2020-02-16 add a script to generate release files
    [PCB.kicad_pcb]
2020-02-17 Fix the button I can't buy... Change part selections for avalibiliby issues
    [PCB.kicad_pcb, RGB.sch, SMT32.sch]
2020-02-20 going to make it (prototype!)
    [PCB.kicad_pcb, PCB.sch, RGB.sch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]
2020-02-21 Appearently buy parts is hard
    [RGB.sch, SMT32.sch]
2020-03-08 adjust the pcb
    [Mounting_PCB-B_Cu.gbl, Mounting_PCB-B_Mask.gbs, Mounting_PCB-B_Paste.gbp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]
2020-03-08 make pads looks better
    [PCB.kicad_pcb]
2020-03-17 small adjustments
    [PCB.kicad_pcb]
2020-03-30 fix some code, trying to figure out the plate
    [Mounting_PCB-B_Cu.gbl, Mounting_PCB-B_Mask.gbs, Mounting_PCB-B_Paste.gbp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]
2020-04-04 change footprint
    [Mounting_PCB.kicad_pcb, Mounting_PCB.sch, PCB.kicad_pcb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]
2020-04-04 adjust edge cut
    [Mounting_PCB.kicad_pcb]
2020-04-05 Cleanup, make everything nice, get ready for making it on JLC
    [Mounting_PCB-B_Cu.gbl, Mounting_PCB-B_Mask.gbs, Mounting_PCB-B_Paste.gbp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]
2020-04-05 adjust layout a tiny bit, make everything nicer
    It's time for V1.0, just double check beffore I sent it to fab
    [PCB.kicad_pcb]
2020-04-05 change stuff so everything export the right way
    [PCB.kicad_pcb, PCB.sch, RGB.sch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]
2020-04-06 fix some detail for 1.0
    [PCB.kicad_pcb, PCB.sch, RGB.sch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]
2020-04-06 v1.1, too many problems I have to fix
    [Mounting_PCB.kicad_pcb, PCB.kicad_pcb, PCB.sch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]
2020-04-18 v2 in progress, update readme
    [PCB.kicad_pcb]
2020-08-26 project clean up
    [PCB.kicad_pcb, SMT32.sch]
2020-08-26 Board clean up
    [PCB.kicad_pcb]

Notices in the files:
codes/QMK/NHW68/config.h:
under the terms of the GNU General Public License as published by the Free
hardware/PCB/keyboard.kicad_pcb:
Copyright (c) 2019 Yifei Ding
